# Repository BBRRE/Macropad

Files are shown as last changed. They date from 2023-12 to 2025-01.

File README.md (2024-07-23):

**Initial render of the Macropad**


**Schematic and PCB wiring**
Schematic
PCB Wiring

**Ordered the PCB from JLCPCB **



Waiting for extra parts.<br>
Soldering and firmware Completed, Will update the repo soon with a better read me and upload the firmware


V2 design: https://imgur.com/a/PmoHiHx

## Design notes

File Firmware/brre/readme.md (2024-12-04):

# brre

brre

*A short description of the keyboard/project*

* Keyboard Maintainer: [Bilaal Bare](https://github.com/Bilaal Bare)
* Hardware Supported: *The PCBs, controllers supported*
* Hardware Availability: *Links to where you can find this hardware*

Make example for this keyboard (after setting up your build environment):

    make brre:default

Flashing example for this keyboard:

    make brre:default:flash

See the [build environment setup](https://docs.qmk.fm/#/getting_started_build_tools) and the [make instructions](https://docs.qmk.fm/#/getting_started_make_guide) for more information. Brand new to QMK? Start with our [Complete Newbs Guide](https://docs.qmk.fm/#/newbs).

## Bootloader

Enter the bootloader in 3 ways:

* **Bootmagic reset**: Hold down the key at (0,0) in the matrix (usually the top left key or Escape) and plug in the keyboard
* **Physical reset button**: Briefly press the button on the back of the PCB - some may have pads you must short instead
* **Keycode in layout**: Press the key mapped to `QK_BOOT` if it is available

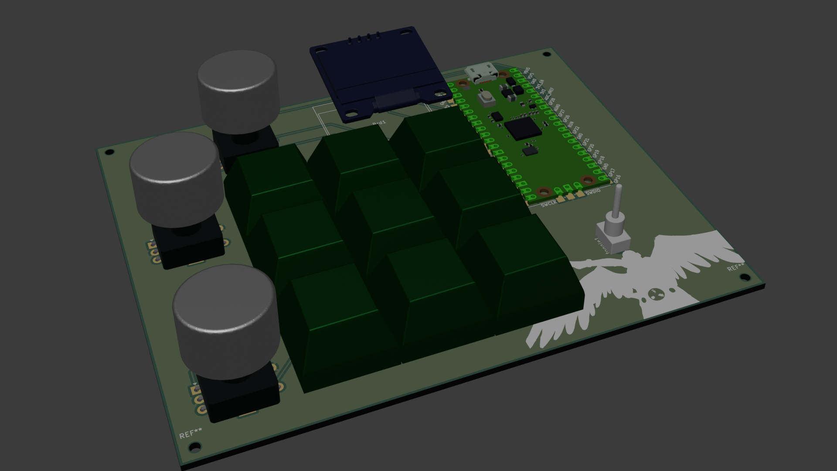
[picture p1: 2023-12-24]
Hardware/3D Model.png

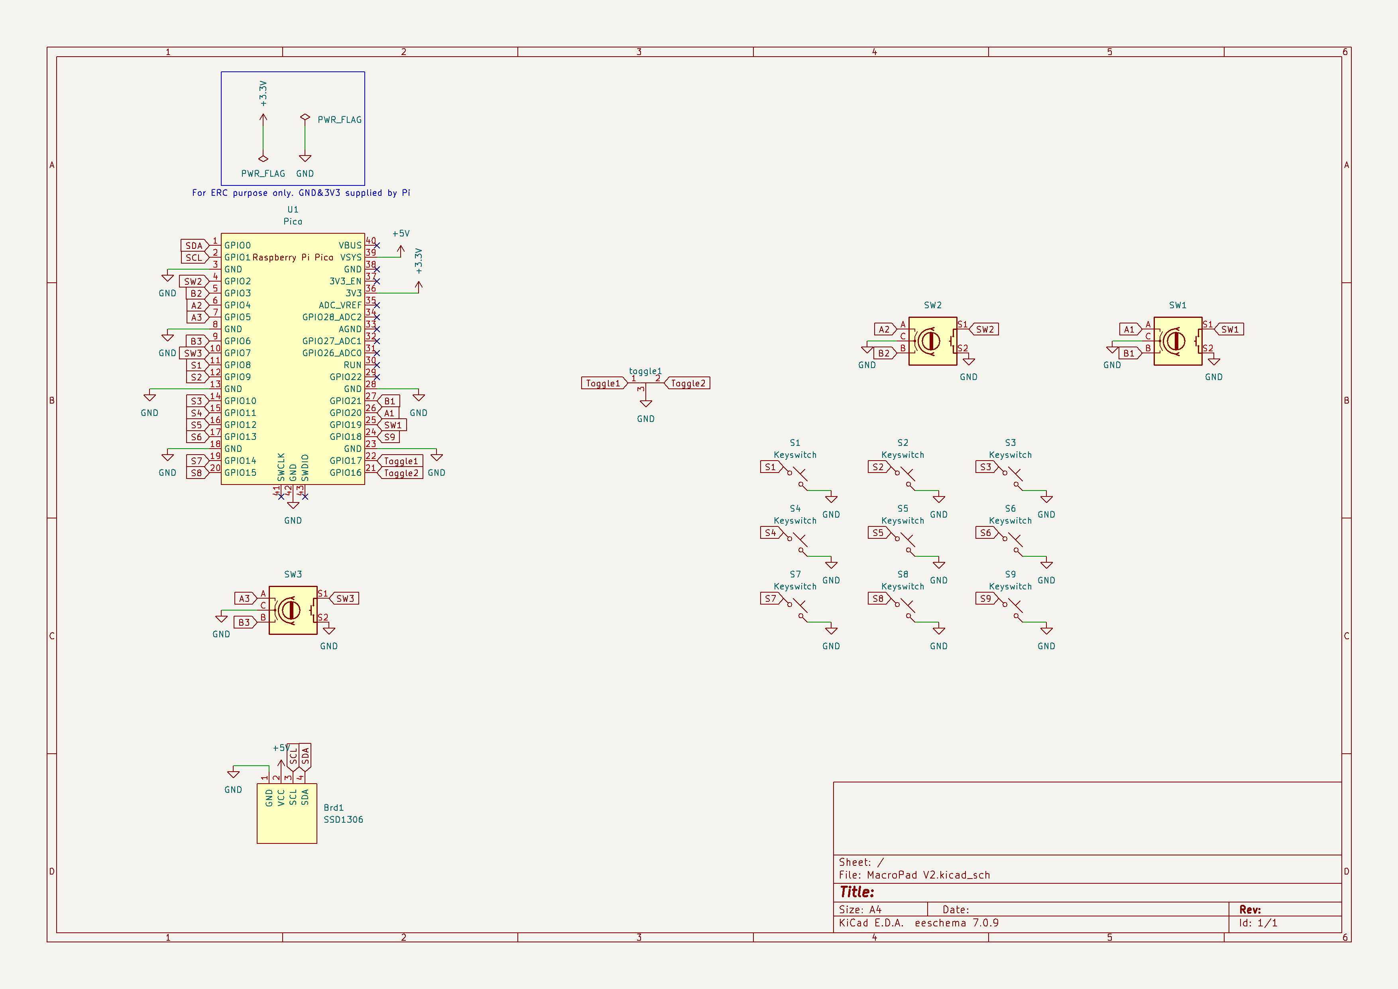
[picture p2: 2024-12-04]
Hardware/MacroPad V2/Schematic.png

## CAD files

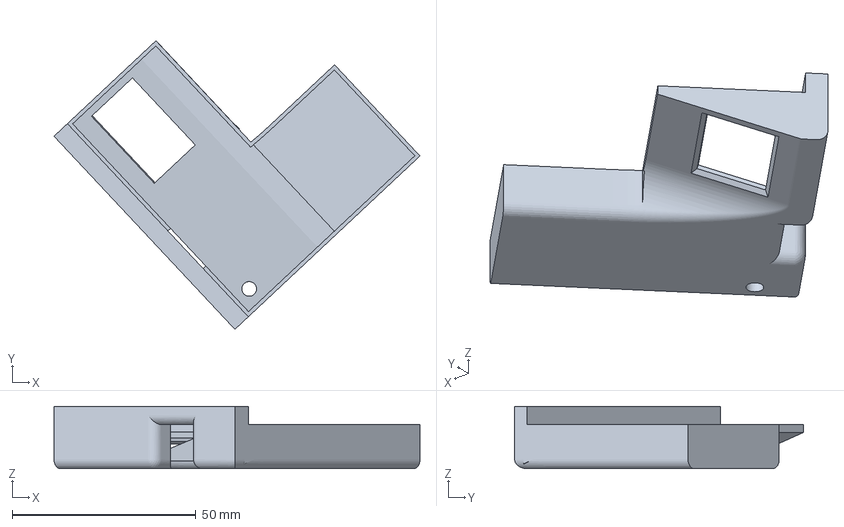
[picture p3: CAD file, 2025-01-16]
Hardware/MacroPad V2/3D Model/Civer 1 v7.3mf
99.6 x 78.6 x 17.0 mm

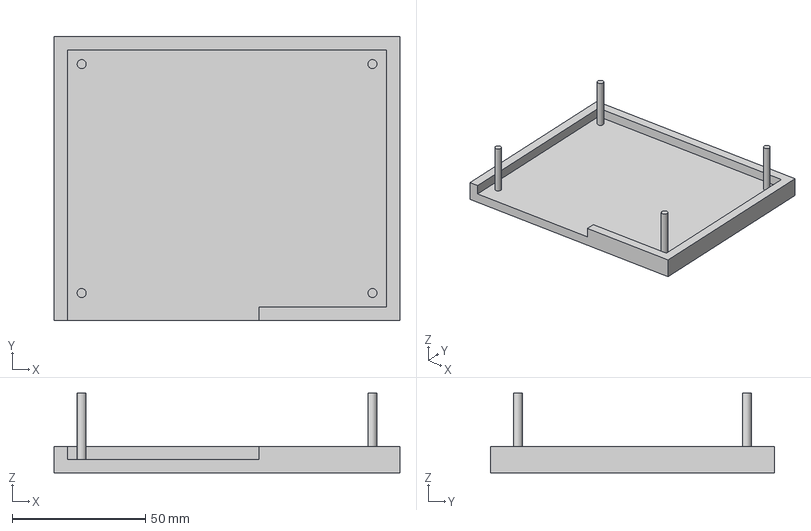
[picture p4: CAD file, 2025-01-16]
Hardware/MacroPad V2/3D Model/Macro Pad case V3 v 4.3mf
129.9 x 106.6 x 30.0 mm

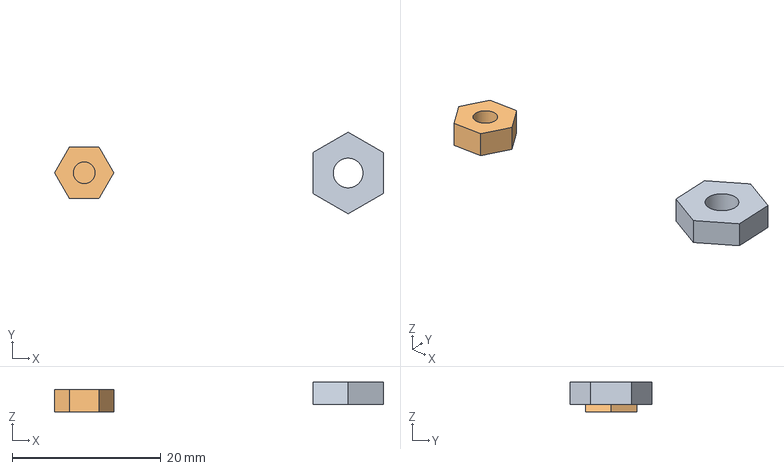
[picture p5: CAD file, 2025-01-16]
Hardware/MacroPad V2/3D Model/(Unsaved).3mf
44.3 x 11.0 x 4.00 mm

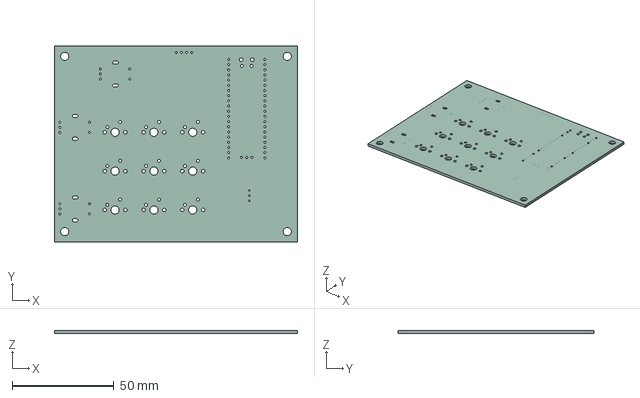
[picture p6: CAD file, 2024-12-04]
Hardware/MacroPad V2/3D Model/PCB-3D Model.step
119.2 x 96.0 x 1.60 mm

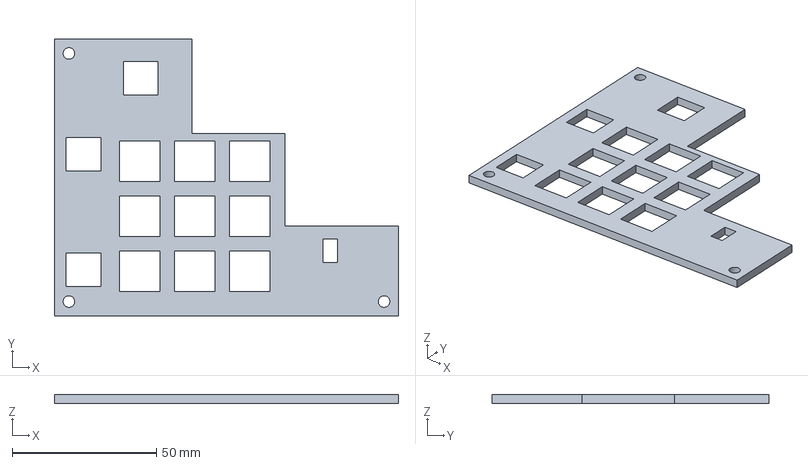
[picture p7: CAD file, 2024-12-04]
Hardware/MacroPad V2/3D Model/Plate V1-BodyPad.3mf
119.2 x 96.0 x 3.00 mm

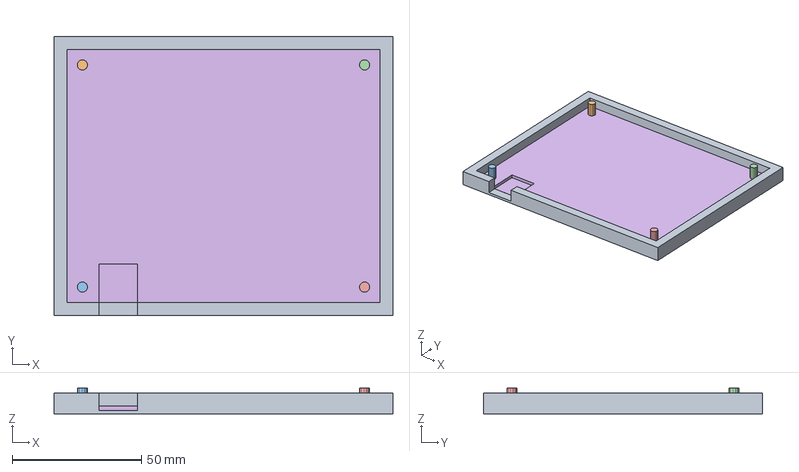
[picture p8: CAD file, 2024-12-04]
Hardware/MacroPad V2/3D Model/Case.3mf
131.2 x 108.0 x 10.0 mm

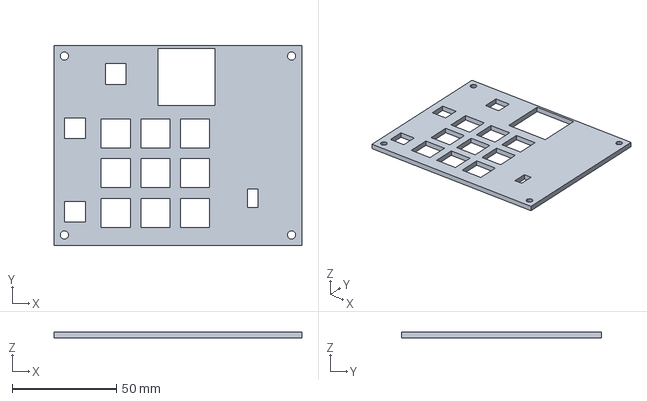
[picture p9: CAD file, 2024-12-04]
Hardware/MacroPad V2/3D Model/Plate.3mf
119.2 x 96.0 x 3.00 mm

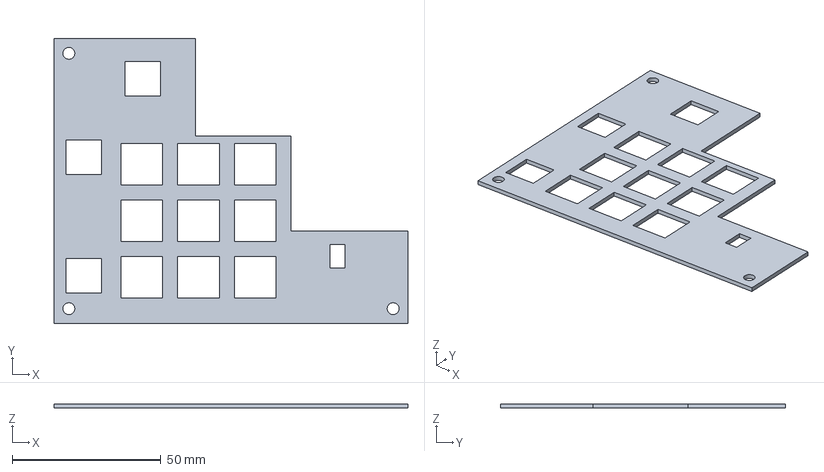
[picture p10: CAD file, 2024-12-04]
Hardware/MacroPad V2/3D Model/Plate V2.3mf
119.2 x 96.0 x 1.50 mm

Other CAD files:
Hardware/MacroPad V2/3D Model/Plate V1.FCStd
Hardware/MacroPad V2/3D Model/Plate V2.obj

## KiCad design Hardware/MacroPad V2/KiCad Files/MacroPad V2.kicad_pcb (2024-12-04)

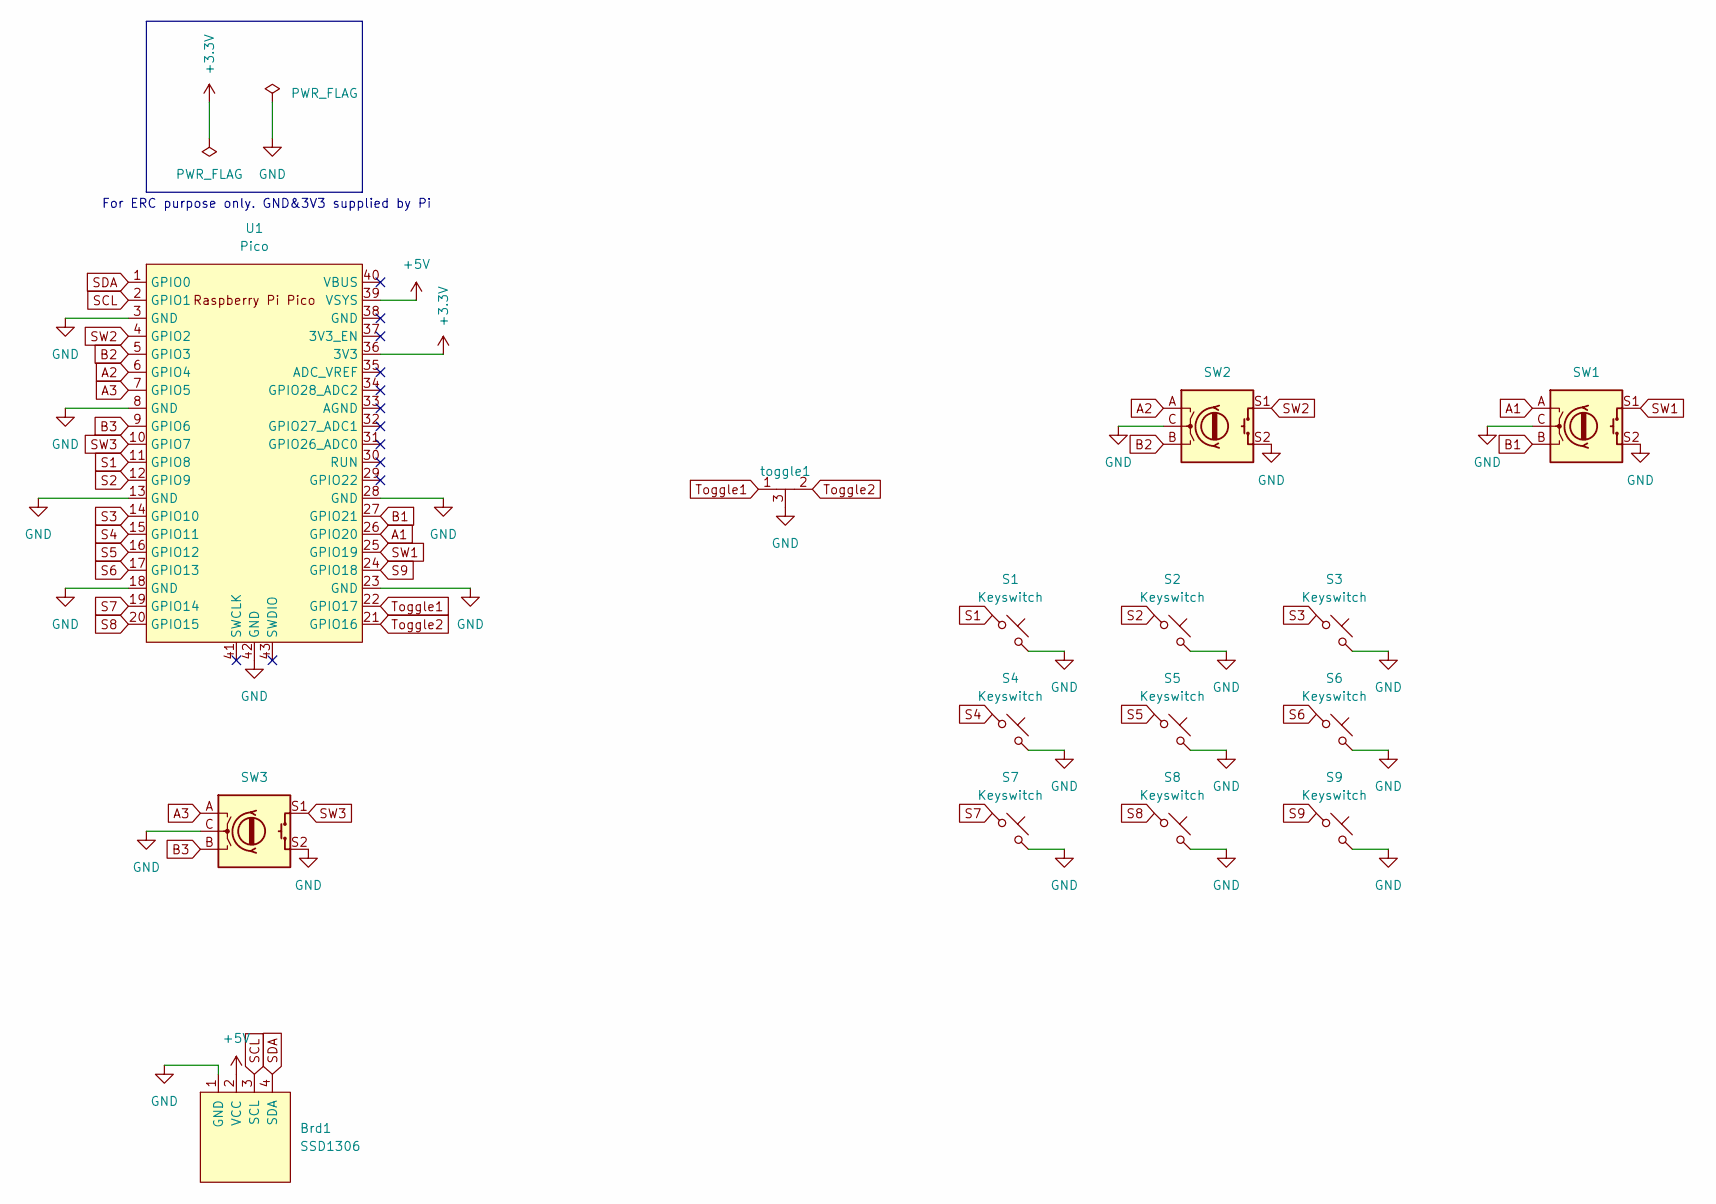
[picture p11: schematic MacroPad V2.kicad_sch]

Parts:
Brd1: SSD1306; 128x64OLED
S1, S2, S3, S4, S5, S6, S7, S8, S9: Keyswitch; MX_PCB_1.00u
SW1, SW2, SW3: RotaryEncoder_Switch; RotaryEncoder_Alps_EC11E-Switch_Vertical_H20mm
U1: Pico; RPi_Pico_SMD_TH
toggle1: Toggle on-off-on

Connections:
+3.3V: U1.36 (3V3)
+5V: Brd1.2 (VCC), U1.39 (VSYS)
A1: SW1.A, U1.26 (GPIO20)
A2: SW2.A, U1.6 (GPIO4)
A3: SW3.A, U1.7 (GPIO5)
B1: SW1.B, U1.27 (GPIO21)
B2: SW2.B, U1.5 (GPIO3)
B3: SW3.B, U1.9 (GPIO6)
GND: Brd1.1 (GND), S1.2, S2.2, S3.2, S4.2, S5.2, S6.2, S7.2, S8.2, S9.2, SW1.C, SW1.S2, SW2.C, SW2.S2, SW3.C, SW3.S2, U1.3 (GND), U1.8 (GND), U1.13 (GND), U1.18 (GND), U1.23 (GND), U1.28 (GND), U1.42 (GND), toggle1.3
S1: S1.1, U1.11 (GPIO8)
S2: S2.1, U1.12 (GPIO9)
S3: S3.1, U1.14 (GPIO10)
S4: S4.1, U1.15 (GPIO11)
S5: S5.1, U1.16 (GPIO12)
S6: S6.1, U1.17 (GPIO13)
S7: S7.1, U1.19 (GPIO14)
S8: S8.1, U1.20 (GPIO15)
S9: S9.1, U1.24 (GPIO18)
SCL: Brd1.3 (SCL), U1.2 (GPIO1)
SDA: Brd1.4 (SDA), U1.1 (GPIO0)
SW1: SW1.S1, U1.25 (GPIO19)
SW2: SW2.S1, U1.4 (GPIO2)
SW3: SW3.S1, U1.10 (GPIO7)
Toggle1: U1.22 (GPIO17), toggle1.1
Toggle2: U1.21 (GPIO16), toggle1.2

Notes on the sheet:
For ERC purpose only. GND&3V3 supplied by Pi

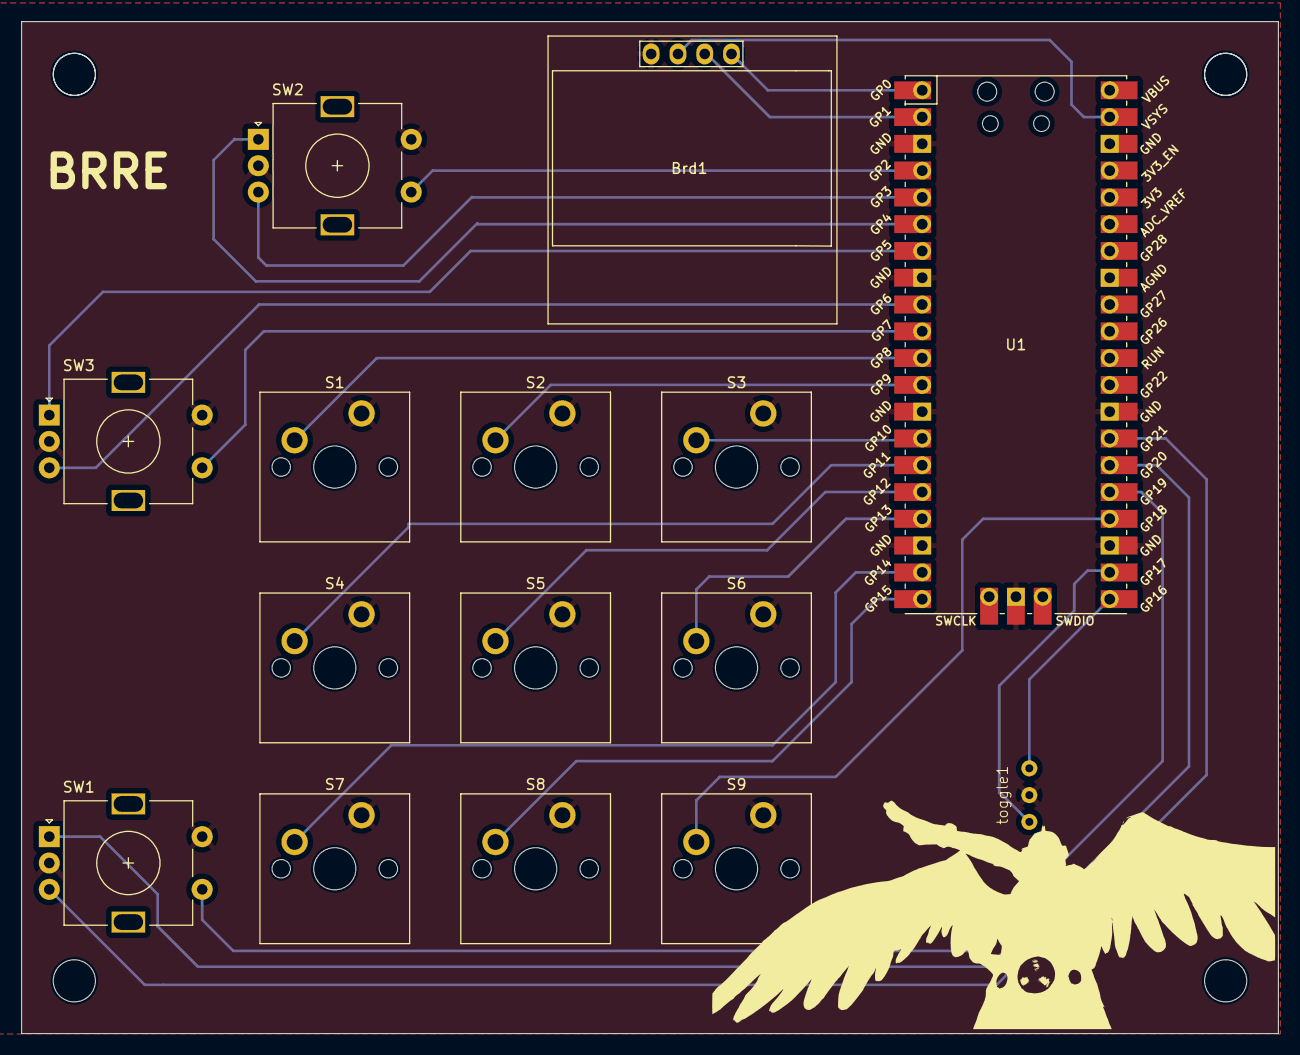
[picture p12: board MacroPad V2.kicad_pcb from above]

Board: 2 copper layers, 119.2 x 96.0 mm, 15 parts (0 on the bottom side), 24 nets.

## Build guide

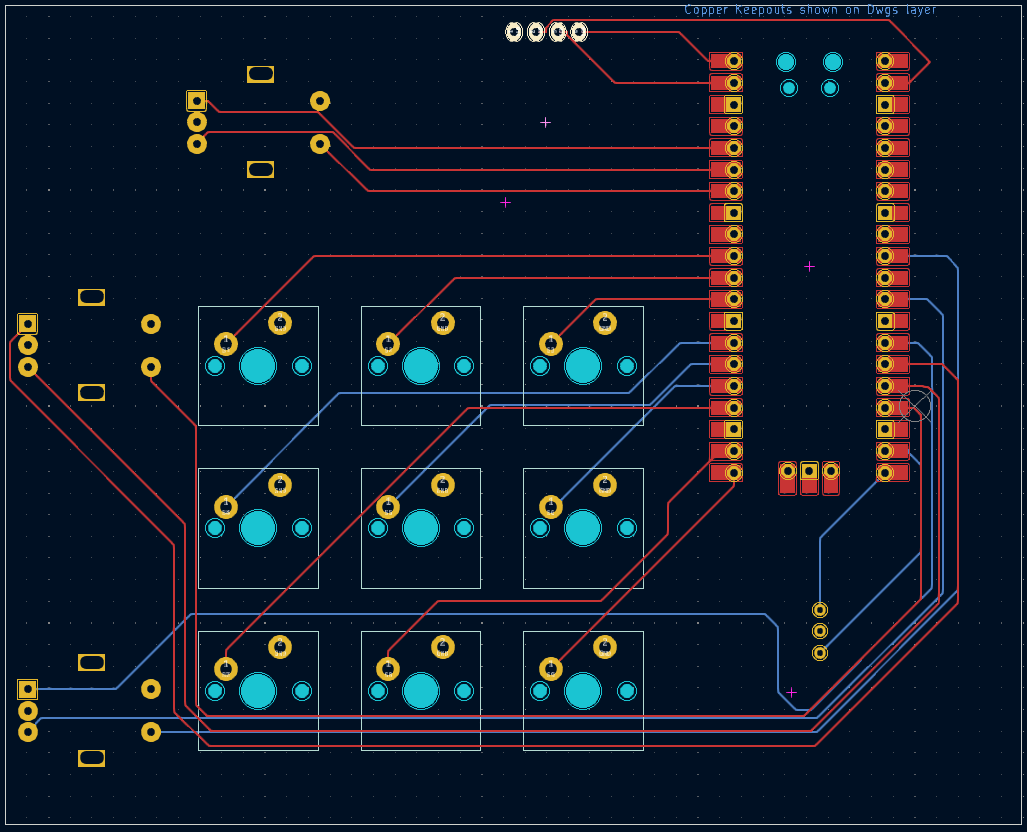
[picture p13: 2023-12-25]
Hardware/MacroPad V2/PCB Wiring.png

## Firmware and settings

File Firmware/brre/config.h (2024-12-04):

// Copyright 2024 Bilaal Bare (@Bilaal Bare)
// SPDX-License-Identifier: GPL-2.0-or-later


#pragma once
#define MATRIX_ROWS 4
#define MATRIX_COLS 3
#define OLED_DISPLAY_128X64

#define I2C1_SDA_PIN GP0
#define I2C1_SCL_PIN GP1
#define I2C_DRIVER I2CD0

#define ENCODERS_PAD_A { GP20 ,  GP4 ,  GP5 }
#define ENCODERS_PAD_B { GP21 ,  GP3 ,  GP6 }

#define DIRECT_PINS {{ GP8 ,  GP9 ,  GP10 },{ GP11 ,  GP12 ,  GP13 },{ GP14 ,  GP15 ,  GP18 }, { GP19 , GP2 ,  GP7 }}

/*
 * Feature disable options
 *  These options are also useful to firmware size reduction.
 */

/* disable debug print */
//#define NO_DEBUG

/* disable print */
//#define NO_PRINT

/* disable action features */
//#define NO_ACTION_LAYER
//#define NO_ACTION_TAPPING
//#define NO_ACTION_ONESHOT

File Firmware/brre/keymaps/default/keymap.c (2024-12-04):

// Copyright 2023 QMK
// SPDX-License-Identifier: GPL-2.0-or-later

#include QMK_KEYBOARD_H

bool is_alt_tab_active = false;
uint16_t alt_gui_timer = 0;


enum layers {
    _BASE,
    _FIRST,
    _SECOND
};

uint8_t get_toggle_switch_layer(void) {
        gpio_set_pin_input_high(GP16);
        gpio_set_pin_input_high(GP17);
    if (gpio_read_pin(GP16) && !gpio_read_pin(GP17)) {
        return _FIRST;
    } else if (!gpio_read_pin(GP16) && gpio_read_pin(GP17)) {
        return _SECOND;
    } else {
        return _BASE;
    }
}

void handle_toggle_switch_layer(void) {
    uint8_t switch_state = get_toggle_switch_layer();
    switch (switch_state) {
        case _BASE:
            layer_on(_BASE);
            layer_off(_FIRST);
            layer_off(_SECOND);
            break;
        case _FIRST:
            layer_off(_BASE);
            layer_on(_FIRST);
            layer_off(_SECOND);
            break;
        case _SECOND:
            layer_off(_BASE);
            layer_off(_FIRST);
            layer_on(_SECOND);
            break;
    }
}

#ifdef OLED_ENABLE

bool oled_task_user(void) {

        static const char codae[] PROGMEM = {
        0x00, 0x00, 0x00, 0x00, 0x00, 0x00, 0x00, 0x00, 0x00, 0x00, 0x00, 0x00, 0x00, 0x00, 0x00, 0x00, 
0x00, 0x00, 0x00, 0x00, 0x00, 0x00, 0x00, 0x00, 0x00, 0x00, 0x00, 0x00, 0x00, 0x00, 0x00, 0x00, 
0x00, 0x00, 0x00, 0x80, 0xc0, 0xc0, 0xe0, 0xf0, 0xf0, 0xf8, 0xfc, 0xfc, 0xfe, 0xfe, 0xfe, 0xfe, 
0xfe, 0xfc, 0xf8, 0xf0, 0xe0, 0x00, 0x00, 0x00, 0x00, 0x00, 0x00, 0x00, 0x00, 0x00, 0x00, 0x00, 
0x00, 0x00, 0x00, 0x00, 0x00, 0x00, 0x00, 0x00, 0x00, 0xc0, 0xf0, 0xf8, 0xfc, 0xfc, 0xfe, 0xfe, 
0xfe, 0xfe, 0xfc, 0xfc, 0xf8, 0xf8, 0xf0, 0xe0, 0xc0, 0xc0, 0x80, 0x00, 0x00, 0x00, 0x00, 0x00, 
0x00, 0x00, 0x00, 0x00, 0x00, 0x00, 0x00, 0x00, 0x00, 0x00, 0x00, 0x00, 0x00, 0x00, 0x00, 0x00, 
0x00, 0x00, 0x00, 0x00, 0x00, 0x00, 0x00, 0x00, 0x00, 0x00, 0x00, 0x00, 0x00, 0x00, 0x00, 0x00, 
0x00, 0x00, 0x00, 0x00, 0x00, 0x00, 0x00, 0x00, 0x00, 0x00, 0x00, 0x00, 0x00, 0x00, 0x00, 0x00, 
0x00, 0x00, 0x00, 0x00, 0x00, 0x00, 0x80, 0x80, 0xc0, 0xe0, 0xe0, 0xf0, 0xf8, 0xf8, 0xfc, 0xfe, 
0xfe, 0xff, 0xff, 0xff, 0xff, 0xff, 0xff, 0xff, 0xff, 0xff, 0xff, 0xff, 0xff, 0xff, 0xff, 0x7f, 
0x3f, 0x3f, 0x1f, 0x0f, 0x03, 0x00, 0x00, 0x00, 0x00, 0x00, 0x00, 0x00, 0x00, 0x00, 0x00, 0x00, 
0x00, 0x00, 0x00, 0x00, 0x00, 0x00, 0x00, 0x00, 0x00, 0x07, 0x0f, 0x1f, 0x3f, 0x7f, 0xff, 0xff, 
0xff, 0xff, 0xff, 0xff, 0xff, 0xff, 0xff, 0xff, 0xff, 0xff, 0xff, 0xff, 0xff, 0xfe, 0xfc, 0xfc, 
0xf8, 0xf8, 0xf0, 0xe0, 0xe0, 0xc0, 0x80, 0x80, 0x00, 0x00, 0x00, 0x00, 0x00, 0x00, 0x00, 0x00, 
0x00, 0x00, 0x00, 0x00, 0x00, 0x00, 0x00, 0x00, 0x00, 0x00, 0x00, 0x00, 0x00, 0x00, 0x00, 0x00, 
0x00, 0x00, 0x00, 0x00, 0x00, 0x00, 0x00, 0x00, 0x00, 0x00, 0x80, 0xc0, 0xc0, 0xe0, 0xe0, 0xf0, 
0xf8, 0xf8, 0xfc, 0xfe, 0xfe, 0xff, 0xff, 0xff, 0xff, 0xff, 0xff, 0xff, 0xff, 0xff, 0xff, 0xff, 
0xff, 0xff, 0xff, 0x7f, 0x3f, 0x3f, 0x1f, 0x0f, 0x0f, 0x07, 0x03, 0x03, 0x01, 0x00, 0x00, 0x00, 
0x00, 0x00, 0x00, 0x00, 0x00, 0x00, 0x00, 0x00, 0x00, 0x00, 0x00, 0x00, 0x00, 0x00, 0x00, 0x00, 
0x00, 0x00, 0x00, 0x00, 0x00, 0x00, 0x00, 0x00, 0x00, 0x00, 0x00, 0x00, 0x00, 0x00, 0x00, 0x00, 
0x01, 0x03, 0x03, 0x07, 0x0f, 0x0f, 0x1f, 0x3f, 0x3f, 0x7f, 0xff, 0xff, 0xff, 0xff, 0xff, 0xff, 
0xff, 0xff, 0xff, 0xff, 0xff, 0xff, 0xff, 0xff, 0xff, 0xfe, 0xfe, 0xfc, 0xf8, 0xf8, 0xf0, 0xe0, 
0xe0, 0xc0, 0xc0, 0x80, 0x00, 0x00, 0x00, 0x00, 0x00, 0x00, 0x00, 0x00, 0x00, 0x00, 0x00, 0x00, 
0x00, 0xc0, 0xe0, 0xf0, 0xf8, 0xfc, 0xfc, 0xfe, 0xff, 0xff, 0xff, 0xff, 0xff, 0xff, 0xff, 0xff, 
0xff, 0xff, 0xff, 0xff, 0xff, 0xff, 0x7f, 0x7f, 0x3f, 0x1f, 0x1f, 0x0f, 0x07, 0x07, 0x03, 0x01, 
0x01, 0x00, 0x00, 0x00, 0x00, 0x00, 0x00, 0x00, 0x00, 0x00, 0x00, 0x00, 0x00, 0x00, 0x00, 0x00, 
0x00, 0x00, 0x00, 0x00, 0x00, 0x00, 0x00, 0x00, 0x00, 0x00, 0x00, 0x00, 0x00, 0x00, 0x00, 0x00, 
0x00, 0x00, 0x00, 0x00, 0x00, 0x00, 0x00, 0x00, 0x00, 0x00, 0x00, 0x00, 0x00, 0x00, 0x00, 0x00, 
0x00, 0x00, 0x00, 0x00, 0x00, 0x00, 0x00, 0x00, 0x00, 0x00, 0x00, 0x00, 0x01, 0x03, 0x03, 0x07, 
0x0f, 0x0f, 0x1f, 0x3f, 0x3f, 0x7f, 0xff, 0xff, 0xff, 0xff, 0xff, 0xff, 0xff, 0xff, 0xff, 0xff, 
0xff, 0xff, 0xff, 0xff, 0xff, 0xff, 0xfe, 0xfc, 0xfc, 0xf8, 0xf0, 0xf0, 0xe0, 0x80, 0x00, 0x00, 
0x00, 0x0f, 0x1f, 0x3f, 0x7f, 0xff, 0xff, 0xff, 0xff, 0xff, 0xff, 0xff, 0xff, 0xff, 0xff, 0xff, 
0xff, 0xff, 0xff, 0xff, 0xff, 0xfc, 0xf8, 0xf8, 0xf0, 0xe0, 0xe0, 0xc0, 0x80, 0x80, 0x00, 0x00, 
0x00, 0x00, 0x00, 0x00, 0x00, 0x00, 0x00, 0x00, 0x00, 0x00, 0x00, 0x00, 0x00, 0x00, 0x00, 0x00, 
0x00, 0x00, 0x00, 0x00, 0x00, 0x00, 0x00, 0x00, 0x00, 0x00, 0x00, 0x00, 0x00, 0x00, 0x00, 0x00, 
0x00, 0x00, 0x00, 0x00, 0x00, 0x00, 0x00, 0x00, 0x00, 0x00, 0x00, 0x00, 0x00, 0x00, 0x00, 0x00, 
0x00, 0x00, 0x00, 0x00, 0x00, 0x00, 0x00, 0x00, 0x00, 0x00, 0x00, 0x00, 0x00, 0x00, 0x00, 0x00, 
0x00, 0x00, 0x80, 0xc0, 0xc0, 0xe0, 0xf0, 0xf0, 0xf9, 0xff, 0xff, 0xff, 0xff, 0xff, 0xff, 0xff, 
0xff, 0xff, 0xff, 0xff, 0xff, 0xff, 0xff, 0xff, 0xff, 0xff, 0xff, 0x7f, 0x3f, 0x1f, 0x00, 0x00, 
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
    };
        static const char media[] PROGMEM = {
        0x00, 0x00, 0x00, 0x00, 0x00, 0x00, 0x00, 0x00, 0x00, 0x00, 0x00, 0x00, 0x00, 0x00, 0x00, 0x00, 
0x00, 0x80, 0x80, 0xc0, 0xc0, 0xe0, 0xe0, 0xe0, 0xe0, 0xf0, 0xf0, 0xf0, 0xf0, 0xf0, 0xf0, 0xf0, 
0xf0, 0xf0, 0xf0, 0xf0, 0xf0, 0xf0, 0xf0, 0xe0, 0xe0, 0xe0, 0xe0, 0xc0, 0xc0, 0x80, 0x80, 0x00, 
0x00, 0x00, 0x00, 0x00, 0x00, 0x00, 0x00, 0x00, 0x00, 0x00, 0x00, 0x00, 0x00, 0x00, 0x00, 0x00, 
0x00, 0x00, 0x00, 0x00, 0x00, 0x00, 0x00, 0x00, 0x00, 0x00, 0x00, 0x00, 0x00, 0x00, 0x80, 0x80, 
0xc0, 0xc0, 0xe0, 0xe0, 0xf0, 0xf0, 0xf0, 0xf8, 0xf8, 0xf8, 0xfc, 0xfc, 0xfc, 0xfc, 0xfc, 0xfc, 
0xfc, 0xfc, 0xfc, 0xfc, 0xfc, 0xfc, 0xf8, 0xf8, 0xf8, 0xf0, 0xf0, 0xf0, 0xe0, 0xe0, 0xc0, 0x80, 
0x80, 0x00, 0x00, 0x00, 0x00, 0x00, 0x00, 0x00, 0x00, 0x00, 0x00, 0x00, 0x00, 0x00, 0x00, 0x00, 
0x00, 0x00, 0x00, 0x00, 0x00, 0x00, 0x00, 0x00, 0x80, 0xe0, 0xf0, 0xf8, 0xfc, 0xfc, 0xfe, 0xff, 
0xff, 0xff, 0xff, 0xff, 0xff, 0xff, 0xff, 0xff, 0xff, 0xff, 0xff, 0xff, 0xff, 0x7f, 0x7f, 0x7f, 
0x7f, 0x7f, 0xff, 0xff, 0xff, 0xff, 0xff, 0xff, 0xff, 0xff, 0xff, 0xff, 0xff, 0xff, 0xff, 0xff, 
0xfe, 0xfc, 0xfc, 0xf8, 0xf0, 0xe0, 0xc0, 0x80, 0x00, 0x00, 0x00, 0x00, 0x00, 0x00, 0x00, 0x00, 
0x00, 0x00, 0x00, 0x00, 0x00, 0x00, 0x80, 0xe0, 0xf0, 0xf8, 0xfc, 0xfe, 0xff, 0xff, 0xff, 0xff, 
0xff, 0xff, 0xff, 0xff, 0xff, 0x7f, 0x3f, 0x3f, 0x3f, 0x1f, 0x1f, 0x1f, 0x1f, 0x0f, 0x0f, 0x1f, 
0x1f, 0x1f, 0x1f, 0x1f, 0x3f, 0x3f, 0x3f, 0x7f, 0x7f, 0xff, 0xff, 0xff, 0xff, 0xff, 0xff, 0xff, 
0xff, 0xff, 0xfe, 0xfc, 0xf8, 0xf0, 0xe0, 0x80, 0x00, 0x00, 0x00, 0x00, 0x00, 0x00, 0x00, 0x00, 
0x00, 0x00, 0x00, 0x00, 0xc0, 0xf0, 0xfc, 0xff, 0xff, 0xff, 0xff, 0xff, 0xff, 0xff, 0xff, 0xff, 
0xff, 0x7f, 0x3f, 0x1f, 0x0f, 0x07, 0x03, 0xf9, 0xfd, 0xfc, 0xfc, 0xf8, 0xf8, 0xf0, 0xf0, 0xe0, 
0xc0, 0xc0, 0x80, 0x80, 0x00, 0x00, 0x01, 0x01, 0x03, 0x07, 0x0f, 0x1f, 0x3f, 0x7f, 0xff, 0xff,
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

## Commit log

2023-12-21 Initial schematic
    3 by 3 keyboard matrix, 3 rotary encoder and a switch
    [MacroPad.kicad_sch]
2023-12-21 3D model
    [prototype macropad.blend]
2023-12-22 New schematic
    Added a small display, rewired the keys to be individually wired, might change the switch I'm using since its way too stiff
    [3D Render.blend]
2023-12-22 Redid the schematic should be finished
    [MacroPad.kicad_sch]
2023-12-22 Electric test work
    [MacroPad.kicad_sch]
2023-12-22 Turns out I didn't pull up resistors for the rotary encoder
    The pi pico has a PULL_UP for this lol
    [MacroPad.kicad_sch]
2023-12-22 last schematic update????
    Oled screen now hooked up on 5V
    [MacroPad.kicad_sch]
2023-12-23 Finall rendistionq
    hopefully
    [MacroPad.kicad_sch]
2023-12-23 Final PCB design
    Image left
2023-12-23 Final version and ready to send
    Yipee
    [MacroPad-B_Cu.gbr, MacroPad-B_Mask.gbr, MacroPad-B_Paste.gbr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]
2023-12-25 Working on a v2
    [MacroPad V2.kicad_pcb, MacroPad V2.kicad_sch]
2023-12-25 Completed V2 and organised fiels
    I rewired the PCB to avoid pins going through each other. YIPEE
    [3D Render.blend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]
2023-12-25 Cleaned up the PCB Wiring
2023-12-25 Rewired to avoid pins
    [MacroPad V2-B_Cu.gbr, MacroPad V2-B_Mask.gbr, MacroPad V2-B_Paste.gbr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]
2024-12-04 Restructer and added Firmware
    [MacroPad V2-B_Cu.gbr, MacroPad V2-B_Mask.gbr, MacroPad V2-B_Paste.gbr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]
2025-01-16 Screeen sizee
    [(Unsaved).3mf, Civer 1 v7.3mf, Macro Pad case V3 v 4.3mf]
